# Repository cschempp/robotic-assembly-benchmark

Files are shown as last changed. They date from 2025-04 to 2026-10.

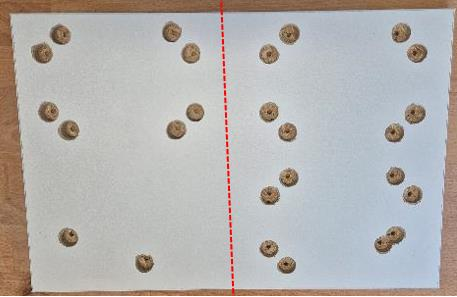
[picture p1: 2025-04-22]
static/images/instructions_board_1.png

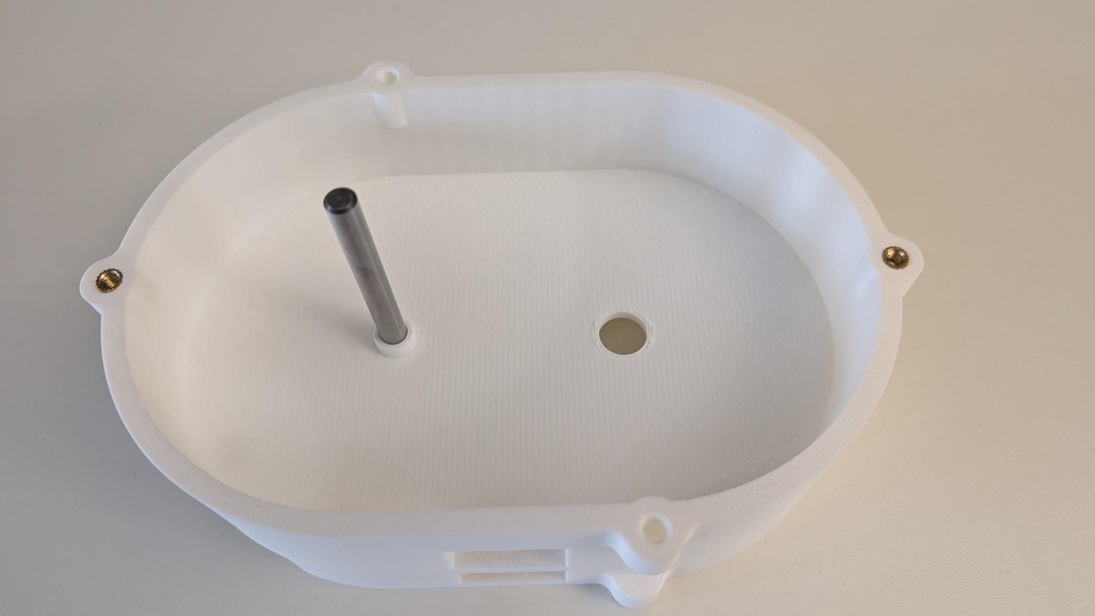
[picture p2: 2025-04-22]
static/images/instructions_housing_middle_bottomview.jpg

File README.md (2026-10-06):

# LABIT: Long-Horizon Robotic Assembly Benchmark for Industrial Tasks
Robot learning has undergone significant advancements in the domain of compliant control and robotic assembly.
The development of novel methodologies has transcended the capacity to address discrete tasks, such as grasping or inserting, and has evolved to encompass the comprehensive construction of entire assemblies.
Conventional benchmarks, which are predominantly focused on single tasks, are no longer adequate to address the complexity and interconnected nature of modern manufacturing processes.
Consequently, the necessity for benchmarks to encompass a broader spectrum of assembly and subassembly steps is becoming apparent.
In light of these developments, we propose LABIT, an industrial robotic assembly benchmark for long-horizon manipulation.
This benchmark encompasses DIN-norm assembly tasks, including screwing, placing, inserting, and snapping, under both high and low tolerance conditions.
The successive nature of these assembly steps implies that prior errors can influence subsequent manipulation.
Consequently, this benchmark is particularly relevant for assessing the robustness of intelligent robotic systems.
The proposed benchmarking protocols and novel performance metric, based on a taxonomy of assembly complexity in conjunction with the comprehensive list of parts and their corresponding CAD models, serve as essential tools for research and development in the field.
To provide a baseline, we evaluate the benchmark using traditional force-position control and report reliability and score metrics per primitive, subtask, assembly category, and subassembly.

## Acknowledgments
Parts of this project page were adopted from the [Nerfies](https://nerfies.github.io/) page.

## Website License
<br />This work is licensed under a <a rel="license" href="http://creativecommons.org/licenses/by-sa/4.0/">Creative Commons Attribution-ShareAlike 4.0 International License</a>.

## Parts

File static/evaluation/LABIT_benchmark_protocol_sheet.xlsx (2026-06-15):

ID | primitive | category | subtask | complexity_tolerance | complexity_geometry | complexity_material | 1 | 2 | 3 | 4 | 5
1 | grip PCB | grasp | PCB | 2 | 1 | 2
2 | place pcb on pins | insert |  | 3 | 2 | 2
3 | snapfit PCB with all 4 pins | snap |  | 3 | 1 | 2
4 | grip plug inside (short cable) | grasp | plug_inside_loose_2 | 2 | 2 | 2
5 | insert plug on PCB | insert |  | 3 | 3 | 2
6 | grip plug inside (long cable) | grasp | plug_inside_loose_1 | 2 | 2 | 2
7 | insert plug on housing middle | insert |  | 3 | 2 | 2
8 | grip plug outside | grasp | plug_outside_loose | 2 | 1 | 2
9 | insert plug on housing middle | insert |  | 3 | 3 | 2
10 | grip rotor | grasp | Rotor | 2 | 1 | 1
11 | place rotor | insert |  | 1 | 1 | 1
12 | grip positioning pin | grasp | positioning_pin_3 | 2 | 1 | 1
13 | place pin in housing | insert |  | 3 | 1 | 3
14 | grip positioning pin | grasp | positioning_pin_4 | 2 | 1 | 1
15 | place pin in housing | insert |  | 3 | 1 | 3
16 | grip housing middle | grasp | housing_middle | 2 | 1 | 2
17 | turn around housing middle | reorient |  | 3 | 3 | 3
18 | attach housing middle to housing bottom | insert |  | 3 | 3 | 3
 | subassembly 1
19 | grip gearwheel 1 | grasp | Gearwheel_Teeth_1 | 1 | 1 | 1
20 | place gearwheel on bolt rotor | insert |  | 2 | 1 | 2
21 | grip gearwheel 2 | grasp | Gearwheel_Teeth_2 | 1 | 1 | 1
22 | place gearwheel on bolt housing middle | insert |  | 2 | 1 | 2
23 | grip positioning pin | grasp | positioning_pin_5 | 2 | 1 | 1
24 | place pin in housing | insert |  | 3 | 1 | 3
25 | grip positioning pin | grasp | positioning_pin_6 | 2 | 1 | 1
26 | place pin in housing | insert |  | 3 | 1 | 3
27 | grip housing top | grasp | housing_top | 2 | 1 | 1
28 | attach housing top to housing middle | insert |  | 3 | 3 | 3
29 | grip screw | grasp | Screw_M5x16_3 | 2 | 1 | 1
30 | place screw in the borehole | insert |  | 3 | 1 | 3
31 | tighten screw | screw |  | 3 | 2 | 3
32 | grip screw | grasp | Screw_M5x16_4 | 2 | 1 | 1
33 | place screw in the borehole | insert |  | 3 | 1 | 3
34 | tighten screw | screw |  | 3 | 2 | 3
 | subassembly 2
35 | grip o-ring | grasp | O-Ring | 3 | 1 | 3
36 | place o-ring in notch | insert |  | 2 | 1 | 3
37 | grip positioning pin | grasp | positioning_pin_1 | 2 | 1 | 1
38 | place pin in housing | insert |  | 3 | 1 | 3
39 | grip positioning pin | grasp | positioning_pin_2 | 2 | 1 | 1
40 | place pin in housing | insert |  | 3 | 1 | 3
41 | grip cover plate | grasp | Coverplatte | 1 | 1 | 1
42 | attach cover plate to housing top | insert |  | 3 | 3 | 3
43 | grip screw | grasp | Screw_M5x16_5 | 2 | 1 | 1
44 | place screw in the borehole | insert |  | 3 | 1 | 3
45 | tighten screw | screw |  | 3 | 2 | 3
46 | grip tube | grasp | Tube | 2 | 1 | 3
47 | place tube on tube nozzle | press fitting |  | 2 | 1 | 3
48 | grip hose clamp | grasp | Clamp | 2 | 2 | 1
49 | insert clamp onto tube | insert |  | 2 | 2 | 2
50 | clamp together | clamp |  | 3 | 1 | 3
51 | grip between middle and bottom housing | grasp | Module | 2 | 1 | 2
52 | rotate the module | reorient |  | 3 | 3 | 3
53 | place the module onto final fixations | insert |  | 2 | 3 | 1
54 | grip screw | grasp | Screw_M5x16_1 | 2 | 1 | 1
55 | place screw in the borehole | insert |  | 3 | 1 | 3
56 | tighten screw | screw |  | 3 | 2 | 3
57 | grip screw | grasp | Screw_M5x16_2 | 2 | 1 | 1
58 | place screw in the borehole | insert |  | 3 | 1 | 3
59 | tighten screw | screw |  | 3 | 2 | 3
 | subassembly 3
 | assembly

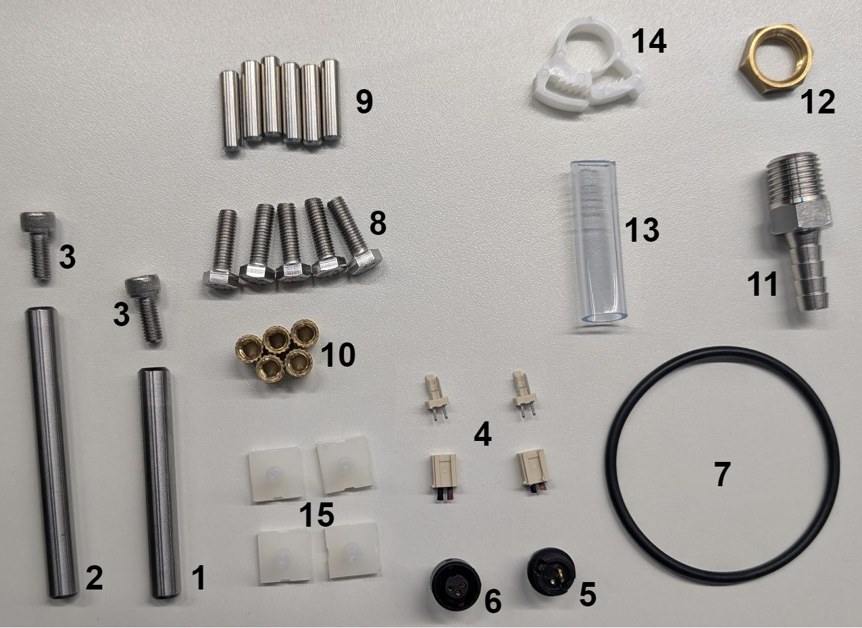
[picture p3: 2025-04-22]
static/images/instructions_parts_list.png

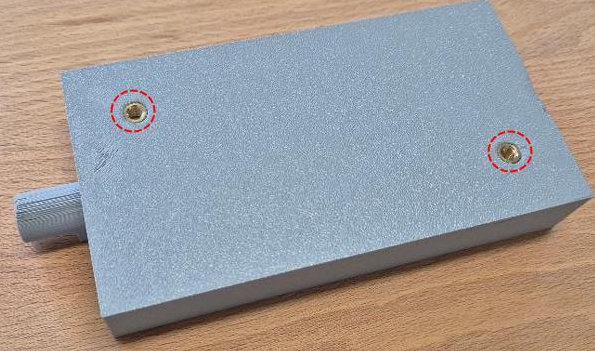
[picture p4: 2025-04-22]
static/images/instruction_parts_supply.png

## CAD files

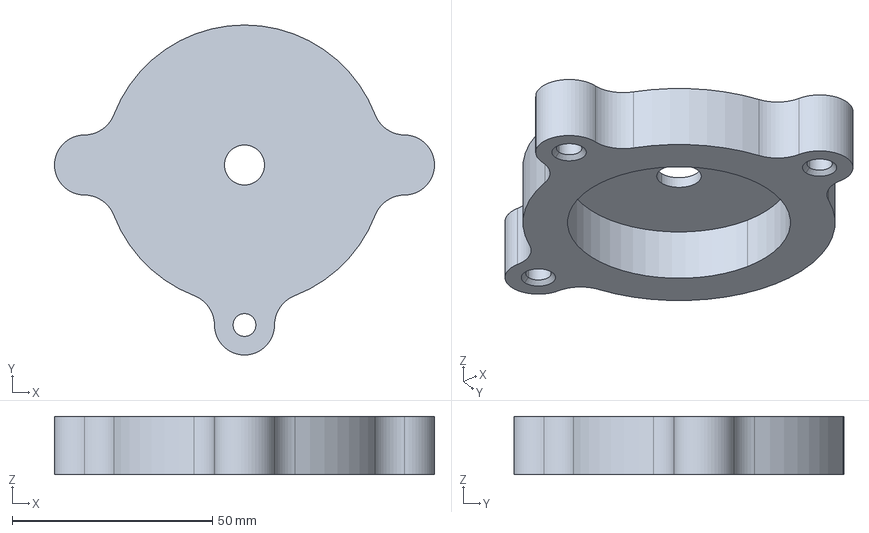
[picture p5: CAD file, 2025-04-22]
static/cad/cad_step/cover_plate.stp
95.0 x 82.5 x 14.5 mm

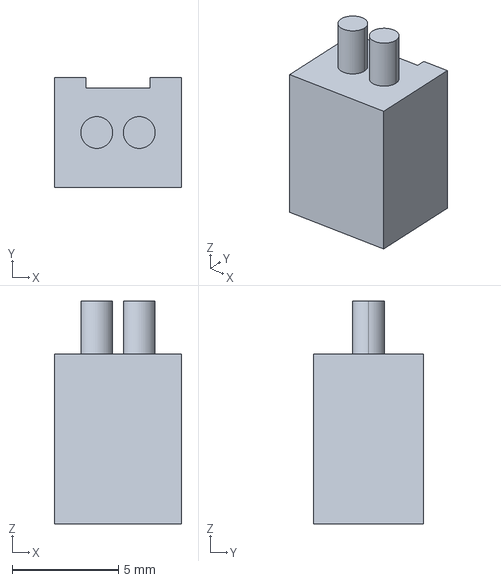
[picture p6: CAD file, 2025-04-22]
static/cad/cad_step/plug_inside_loose.stp
6.00 x 5.20 x 10.5 mm

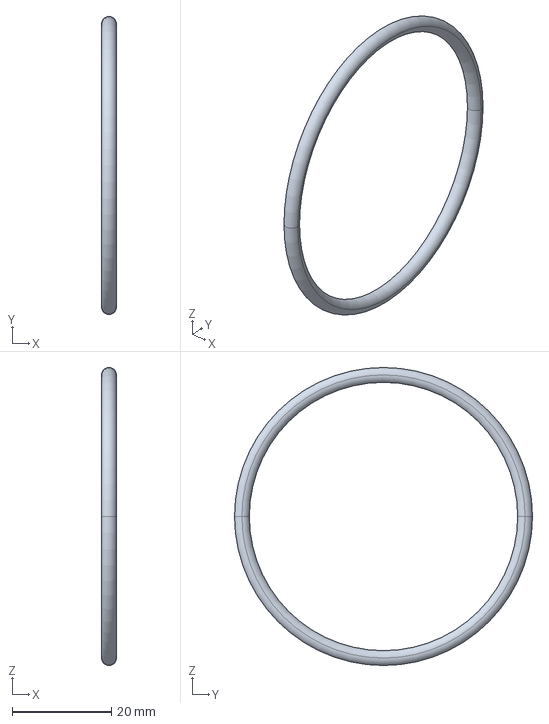
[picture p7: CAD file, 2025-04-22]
static/cad/cad_step/o_ring.stp
3.00 x 60.2 x 60.2 mm

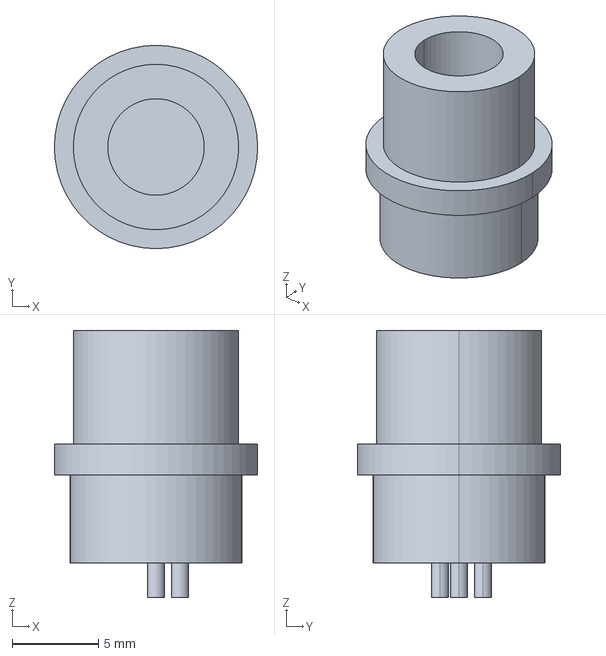
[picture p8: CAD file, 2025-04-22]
static/cad/cad_step/plug_outside_loose.stp
11.8 x 11.8 x 15.5 mm

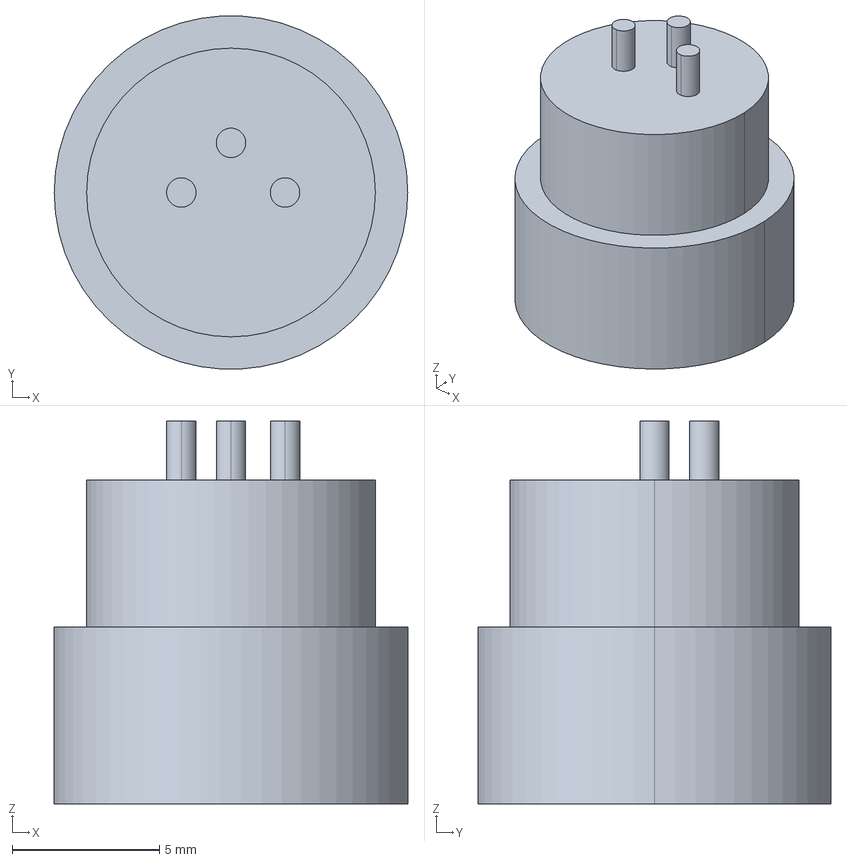
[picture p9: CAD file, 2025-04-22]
static/cad/cad_step/plug_outside_fixed.stp
12.0 x 12.0 x 13.0 mm

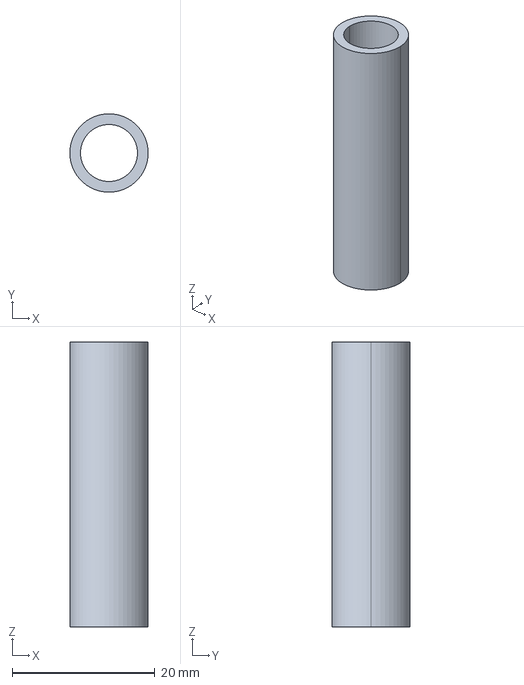
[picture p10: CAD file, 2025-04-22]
static/cad/cad_step/tube.stp
11.0 x 11.0 x 40.0 mm

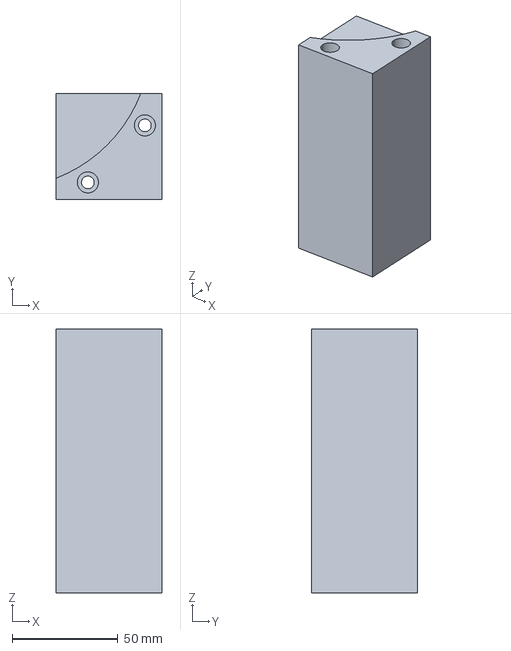
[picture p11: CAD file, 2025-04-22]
static/cad/cad_step/fixation_on_plate_1.stp
50.0 x 50.0 x 125.0 mm

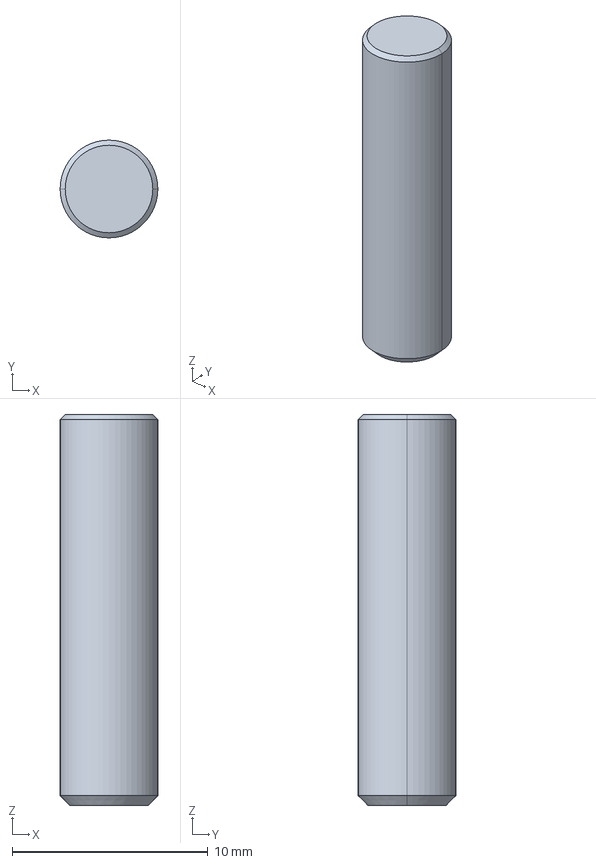
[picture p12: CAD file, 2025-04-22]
static/cad/cad_step/positioning_pin_d5_20.stp
5.00 x 5.00 x 20.0 mm

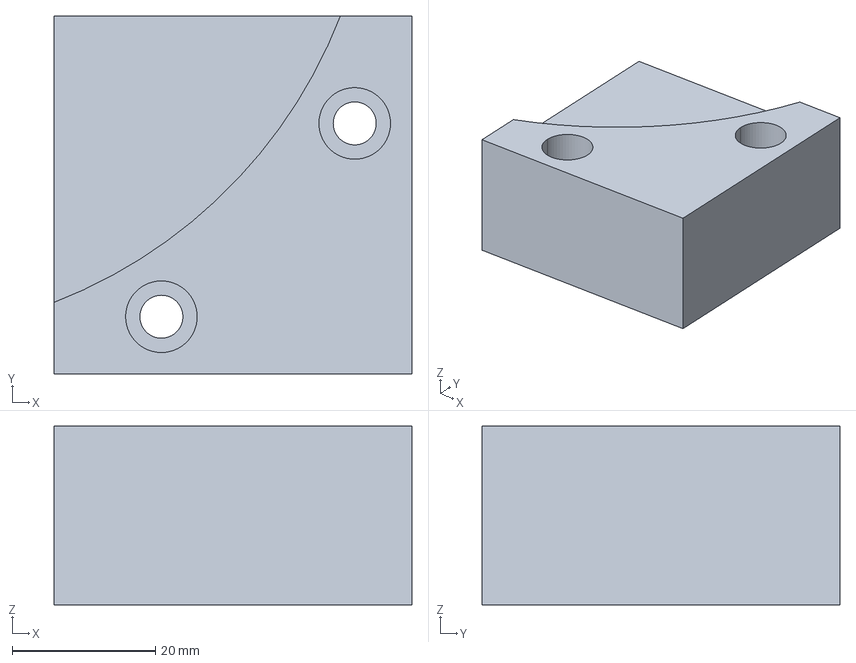
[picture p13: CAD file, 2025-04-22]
static/cad/cad_step/fixation_on_plate_2.stp
50.0 x 50.0 x 25.0 mm

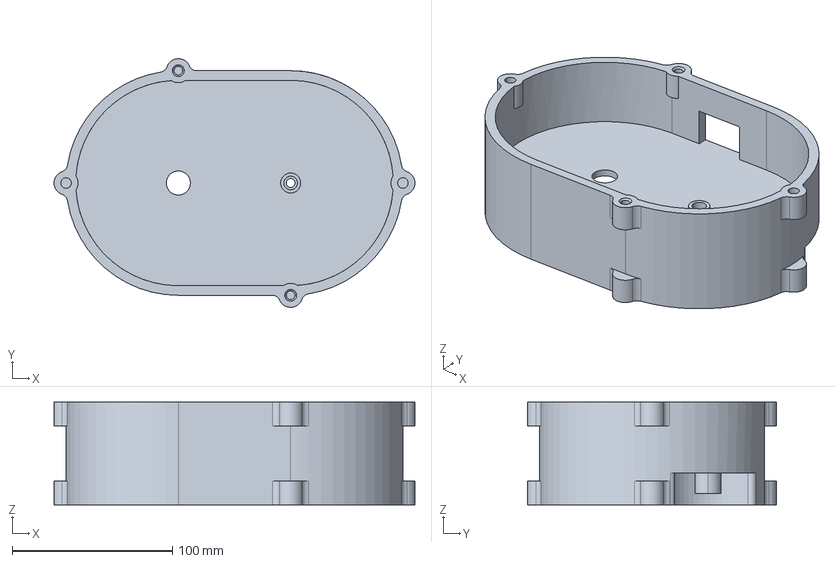
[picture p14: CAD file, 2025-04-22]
static/cad/cad_step/housing_middle.stp
225.0 x 155.0 x 64.0 mm

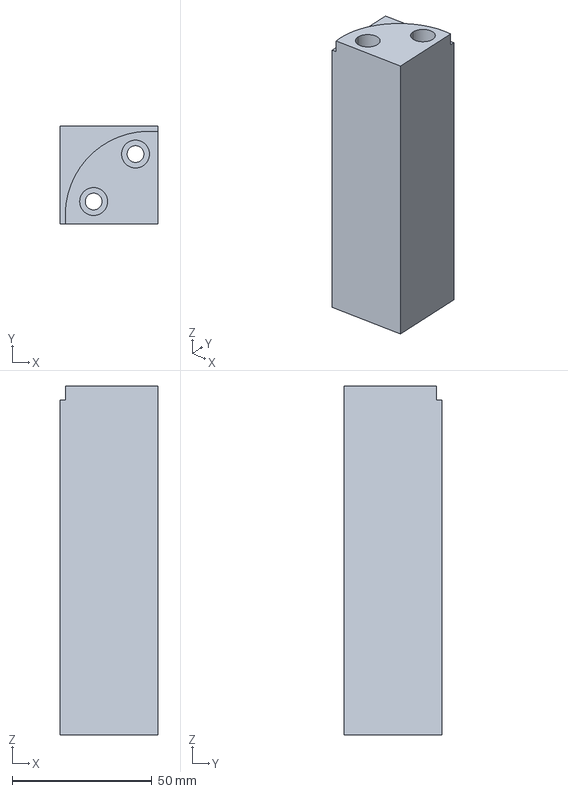
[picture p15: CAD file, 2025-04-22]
static/cad/cad_step/fixation_on_plate_3.stp
35.0 x 35.0 x 125.0 mm

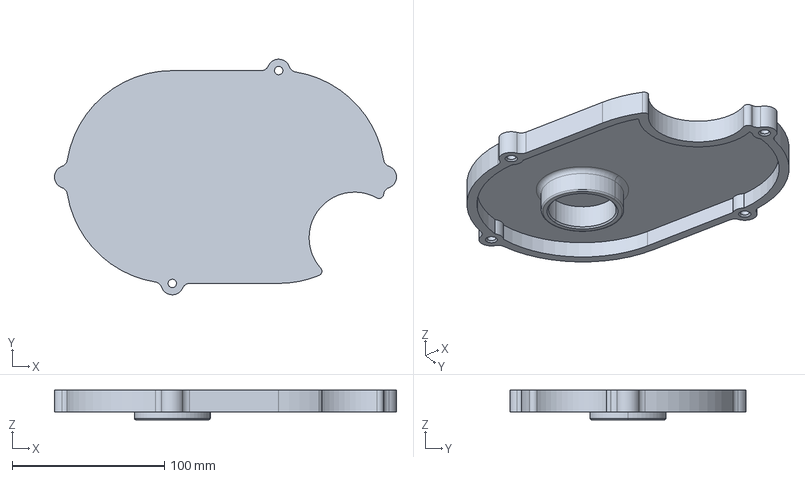
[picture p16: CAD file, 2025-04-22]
static/cad/cad_step/housing_bottom_printed_part.stp
225.0 x 155.0 x 19.5 mm

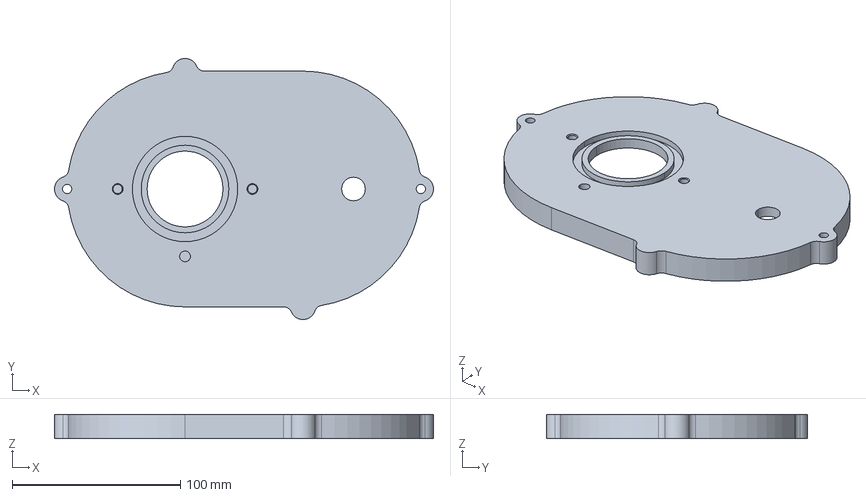
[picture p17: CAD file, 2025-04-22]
static/cad/cad_step/housing_top.stp
225.0 x 155.0 x 14.5 mm

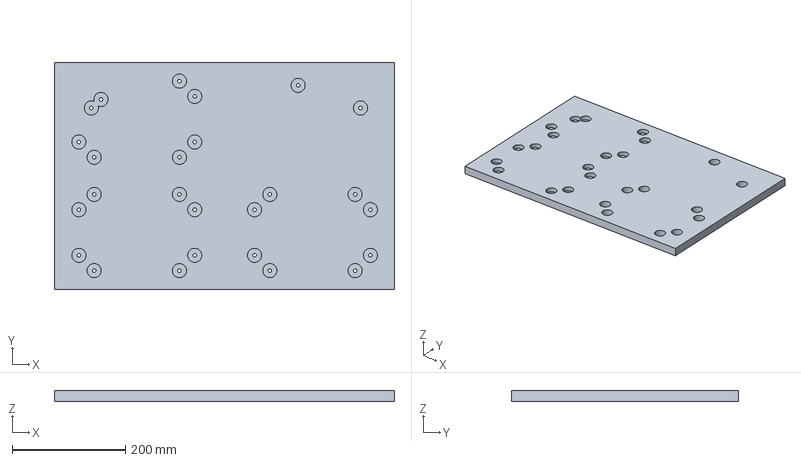
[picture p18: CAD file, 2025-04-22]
static/cad/cad_step/plate_benchmark.stp
600.0 x 400.0 x 19.0 mm

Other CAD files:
static/cad/cad_step/fixation_on_plate_0.stp
static/cad/cad_step/parts_supply.stp
static/cad/cad_step/threaded_insert_m5_length_5_8.stp
static/cad/cad_step/pcb.stp
static/cad/cad_prt_asm/bolt_middle_housing.prt
static/cad/cad_prt_asm/bolt_rotor.prt
static/cad/cad_prt_asm/cover_plate.prt
static/cad/cad_prt_asm/fixation_on_plate_0.prt
static/cad/cad_prt_asm/fixation_on_plate_1.prt
static/cad/cad_prt_asm/fixation_on_plate_2.prt
static/cad/cad_prt_asm/fixation_on_plate_3.prt
static/cad/cad_prt_asm/gearwheel_teeth_35_mod_2.prt
static/cad/cad_prt_asm/housing_bottom_printed_part.prt
static/cad/cad_prt_asm/housing_middle.prt
static/cad/cad_prt_asm/housing_top.prt
static/cad/cad_prt_asm/nut_tube.prt
static/cad/cad_prt_asm/o_ring.prt
static/cad/cad_prt_asm/parts_box.prt
static/cad/cad_prt_asm/parts_plate.prt
static/cad/cad_prt_asm/parts_supply.prt
static/cad/cad_prt_asm/pcb.prt
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

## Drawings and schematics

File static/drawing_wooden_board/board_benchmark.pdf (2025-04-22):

t=19

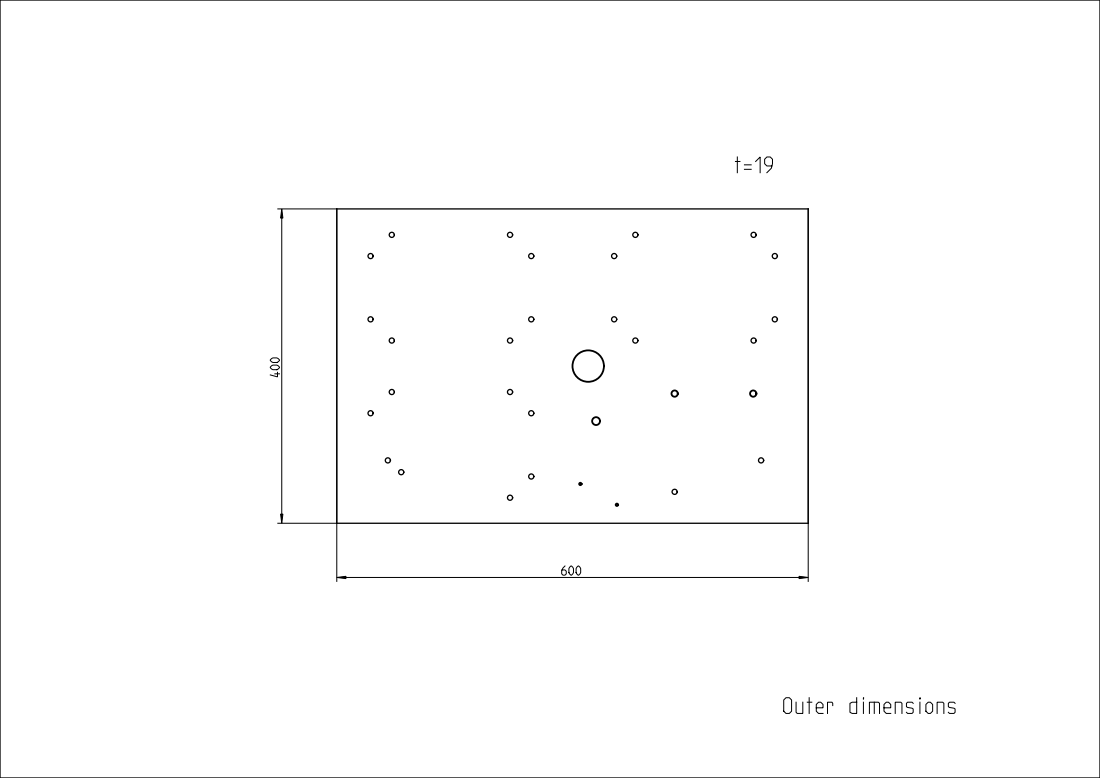
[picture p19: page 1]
Outer dimensions

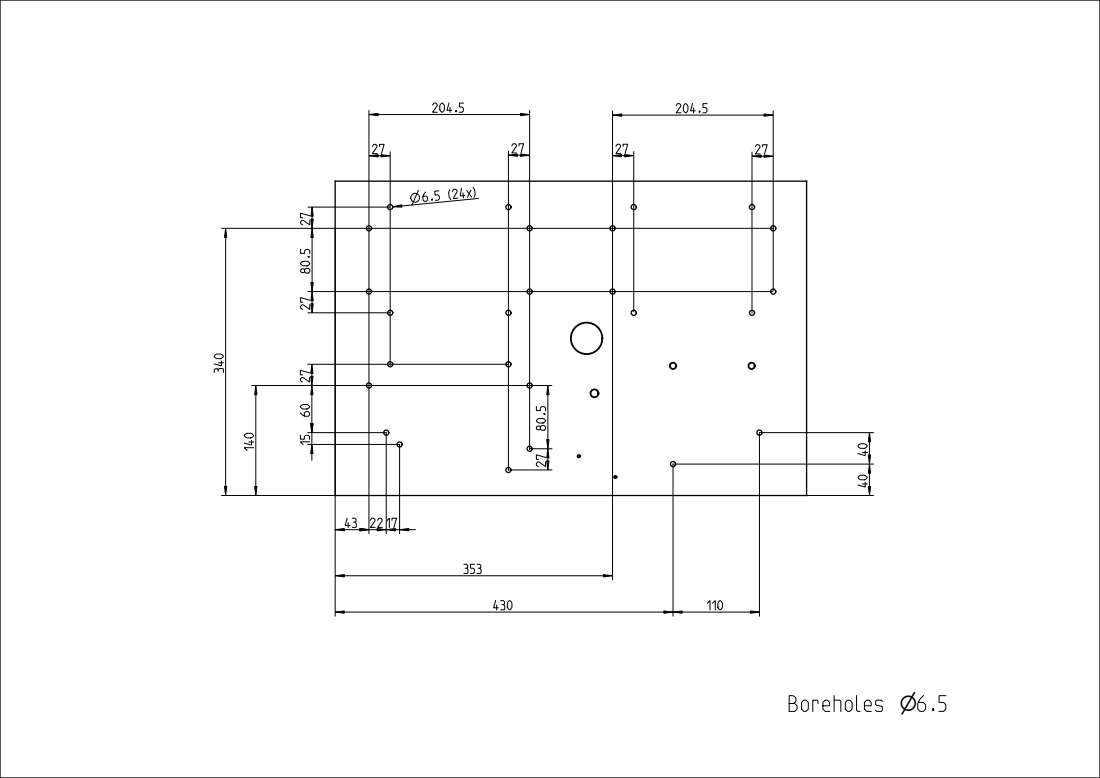
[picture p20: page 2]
Boreholes ⌀6.5

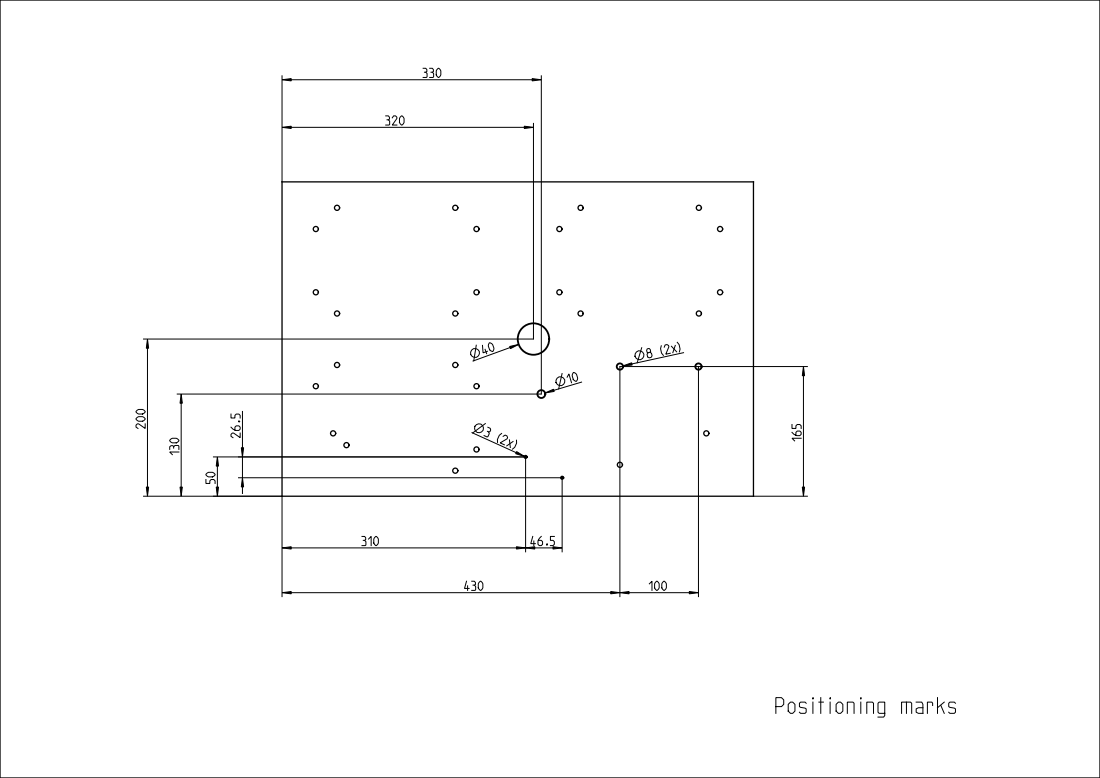
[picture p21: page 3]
Positioning marks

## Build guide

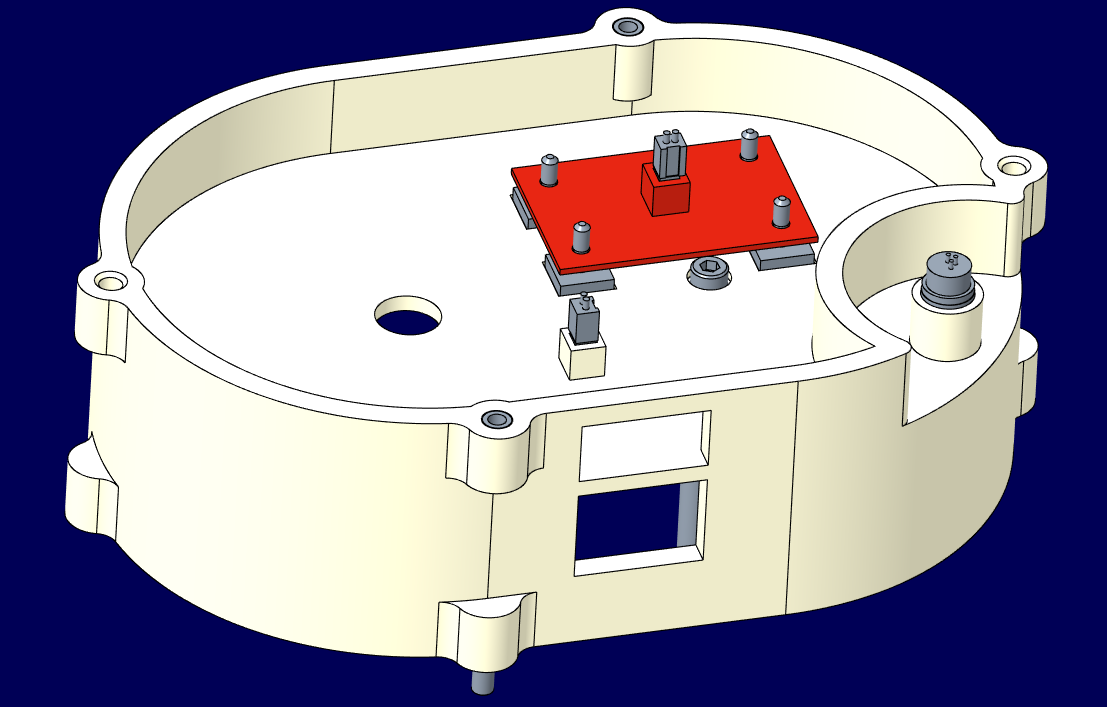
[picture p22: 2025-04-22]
static/images/housing_middle_assembly.png

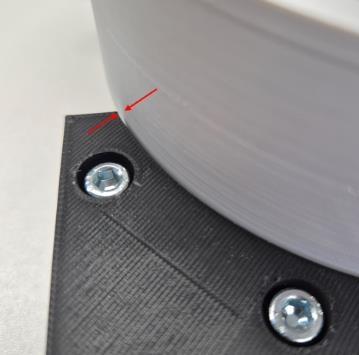
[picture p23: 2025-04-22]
static/images/instructions_fixations_0.png

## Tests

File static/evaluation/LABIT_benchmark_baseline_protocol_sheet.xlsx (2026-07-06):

ID | primitive | category | subtask | complexity_tolerance | complexity_geometry | complexity_material | 1 | 2 | 3 | 4 | 5
1 | grip PCB | grasp | PCB | 2 | 1 | 2 | 1 | 1 | 1 | 1 | 1
2 | place pcb on pins | insert |  | 3 | 2 | 2 | 0 | 1 | 1 | 1 | 1
3 | snapfit PCB with all 4 pins | snap |  | 3 | 1 | 2 | 1 | 1 | 1 | 1 | 1
4 | grip plug inside (short cable) | grasp | plug_inside_loose_2 | 2 | 2 | 2 | 1 | 1 | 1 | 1 | 1
5 | insert plug on PCB | insert |  | 3 | 3 | 2 | 1 | 1 | 1 | 1 | 0
6 | grip plug inside (long cable) | grasp | plug_inside_loose_1 | 2 | 2 | 2 | 1 | 1 | 1 | 1 | 1
7 | insert plug on housing middle | insert |  | 3 | 2 | 2 | 1 | 1 | 1 | 1 | 1
8 | grip plug outside | grasp | plug_outside_loose | 2 | 1 | 2 | 1 | 1 | 1 | 1 | 1
9 | insert plug on housing middle | insert |  | 3 | 3 | 2 | 1 | 0 | 0 | 1 | 0
10 | grip rotor | grasp | Rotor | 2 | 1 | 1 | 1 | 1 | 1 | 1 | 1
11 | place rotor | insert |  | 1 | 1 | 1 | 1 | 1 | 1 | 1 | 1
12 | grip positioning pin | grasp | positioning_pin_3 | 2 | 1 | 1 | 1 | 1 | 1 | 1 | 1
13 | place pin in housing | insert |  | 3 | 1 | 3 | 1 | 1 | 1 | 1 | 1
14 | grip positioning pin | grasp | positioning_pin_4 | 2 | 1 | 1 | 1 | 1 | 1 | 1 | 1
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

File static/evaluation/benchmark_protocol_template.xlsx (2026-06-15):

ID | primitive | category | subtask | complexity_tolerance | complexity_geometry | complexity_material | 1 | 2 | 3 | 4 | 5
1
2
3
4
5
6
7
8
9
10
11
12
13
14
15
16
17
18
 | subassembly 1
19
20
21
22
23
24
25
26
27
28
29
30
31
32
33
34
 | subassembly 2
35
36
37
38
39
40
41
42
43
44
45
46
47
48
49
50
51
52
53
54
55
56
57
58
59
 | subassembly 3
 | assembly

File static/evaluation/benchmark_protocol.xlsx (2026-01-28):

 |  | process | category | complexity_tolerance | complexity_geometry | complexity_material | 1 | 2 | 3 | 4 | 5
PCB | 1 | grip PCB | grasping | 3 | 1 | 3 | 1 | 1 | 1 | 1 | 1
 | 2 | place pcb on pins | insertion | 2 | 2 | 2 | 0 | 1 | 1 | 1 | 1
 | 3 | snapfit PCB with all 4 pins | insertion | 3 | 1 | 3 | 1 | 1 | 1 | 1 | 1
Plug_inside_loose_2 | 4 | grip plug inside (short cable) | insertion | 2 | 2 | 2 | 1 | 1 | 1 | 1 | 1
 | 5 | insert plug on PCB | insertion | 1 | 2 | 2 | 1 | 1 | 1 | 1 | 0
Plug_inside_loose_1 | 6 | grip plug inside (long cable) | grasping | 2 | 1 | 3 | 1 | 1 | 1 | 1 | 1
 | 7 | insert plug on housing middle | insertion | 3 | 2 | 3 | 1 | 1 | 1 | 1 | 1
Plug_outside_loose | 8 | grip plug outside | grasping | 3 | 1 | 3 | 1 | 1 | 1 | 1 | 1
 | 9 | insert plug on housing middle | insertion | 1 | 3 | 3 | 1 | 0 | 0 | 1 | 0
Rotor | 10 | grip rotor | grasping | 2 | 3 | 1 | 1 | 1 | 1 | 1 | 1
 | 11 | place rotor | insertion | 1 | 1 | 2 | 1 | 1 | 1 | 1 | 1
Pin 3 | 12 | grip positioning pin | grasping | 3 | 3 | 2 | 1 | 1 | 1 | 1 | 1
 | 13 | place pin in housing | insertion | 2 | 1 | 3 | 1 | 1 | 1 | 1 | 1
Pin 4 | 14 | grip positioning pin | grasping | 3 | 3 | 1 | 1 | 1 | 1 | 1 | 1
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

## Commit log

2025-04-22 major changes
    [benchmark_protocol.xlsx, benchmark_protocol_template.xlsx, bolt_middle_housing.prt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]
2026-01-28 updated protocol and eval scripts
    [benchmark_protocol.xlsx, benchmark_protocol_template.xlsx]
2026-01-28 additional initial benchmark setups
    [parts_box.prt, parts_plate.prt]
2026-06-15 added LABIT template with predefined values.
    [LABIT_benchmark_protocol_sheet.xlsx]
2026-06-15 updated empty template to have same structure as LABIT protocol.
    [benchmark_protocol_template.xlsx]
2026-07-06 added baseline results.
    [LABIT_benchmark_baseline_protocol_sheet.xlsx]
2026-10-02 _top on all nav buttons
2026-10-05 Update GitHub link in material.html
2026-10-06 Revise LABIT benchmark description in README
    Updated the README to clarify the LABIT benchmark and its relevance in robotic assembly tasks.
